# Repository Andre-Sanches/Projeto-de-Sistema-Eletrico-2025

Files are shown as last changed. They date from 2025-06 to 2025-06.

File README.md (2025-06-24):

# Projeto-de-Sistema-Eletrico-2025
Projeto Elétrico exemplo realizado no curso de Engenharia Elétrica - FHO

⚠️ Restrições de Uso  

Este material é fornecido "no estado em que se encontra" e destina-se unicamente a consulta. Qualquer uso comercial, seja direto ou indireto, é estritamente proibido sem autorização expressa do autor.
Para outras finalidades ou solicitações de uso que não se enquadrem nas condições de uso acadêmico e não comercial, por favor, entre em contato com o autor.

✉️ Contato

André Rodrigues Sanches
Seu Email: andrerodriguessanches@hotmail.com
LinkedIn: www.linkedin.com/in/andre-rodrigues-sanches

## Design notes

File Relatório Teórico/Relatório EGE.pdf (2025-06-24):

1

CENTRO UNIVERSITÁRIO DA FUNDAÇÃO HERMÍNIO OMETTO NÚCLEO

DE ENGENHARIA

ENGENHARIA ELÉTRICA

Projetos de sistemas elétricos

Projeto elétrico de uma indústria de papel

Nome completo | RA
André Rodrigues Sanches | 109177
Gabriel Henrique Leme | 109551
Gustavo Ferreira | 110353
Matheus de Souza Cardoso | 108925

Araras

Junho 2025

### 1. INTRODUÇÃO

A energia elétrica tornou-se fundamental na vida das pessoas. Só no Brasil, segundo o

IBGE, 99,8% das residências brasileiras possuem acesso à energia elétrica, consequentemente,

a busca por profissionais que executam serviços de instalações elétricas ficaram cada vez

maiores. As instalações elétricas são compostas por diversos elementos, que vão desde

condutores básicos em qualquer instalação até dispositivos de automação, aplicados em

instalações mais complexas. O conhecimento desses elementos e de sua forma correta de

utilização é necessário aos projetistas para garantir instalações confortáveis e seguras a seus

usuários.

A segurança das instalações elétricas é um aspecto fundamental e está previsto em

algumas normas brasileiras. As normas existem para padronizar, trazer igualdade às instalações

elétricas e melhorar o âmbito de qualidade das mesmas e foi criada justamente para garantir a

segurança de equipamentos e pessoas (SILVA et al., 2019)

Como base, utilizamos da NBR5410:2004, que existe para regulamentar a execução dos

projetos elétricos em baixa tensão, ela surgiu pela preocupação com este tipo de instalação e

traz em suas especificações as justas explicações e vantagens quanto as instalações prediais que

atendem e seguem regularmente a norma. A mesma se aplica principalmente às instalações

elétricas de edificações, qualquer que seja seu uso (residencial, comercial, público, industrial,

de serviços, agropecuário, hortigranjeiro etc.), incluindo as pré-fabricadas, sejam instalações

novas ou reformas

É imprescindível ter certeza de realizar o processo de dimensionamento e execução de

instalação elétrica de maneira correta e com segurança para evitar futuros problemas, pois estes

processos uma vez feitos de maneira imprudente podem ocasionar diversos transtornos durante

e após construção (PORTE, 2018).

Portanto, este relatório detalha o projeto elétrico de uma pequena indústria de papel,

estruturada em três áreas produtivas distintas. O relatório visa abranger desde o

dimensionamento de condutores e dispositivos de proteção até a análise de curtos-circuitos e o

projeto luminotécnico de uma das áreas. A relevância desse relatório simulando o real retrata

para a Engenharia de Segurança do Trabalho a minimização de riscos de acidentes e falhas

operacionais, promovendo um ambiente de trabalho seguro, além disso, para a instituição

representa a aplicação prática e integrada de conhecimentos teóricos estudados em todo

decorrer do curso.

### 2. DESENVOLVIMENTO

### 2.1 Dados iniciais do cliente

Como base para o início do projeto do cliente é fundamental o entendimento das áreas

e dados solicitados pelo mesmo. Abaixo segue tais descrições:

Figura 1 - Distribuição de setores dentro da indústria de papel

Figura 2 - Dados do cliente

### 2.2 Motores

A partir do conhecimento dos dados iniciais do cliente, é começado o dimensionamento

dos equipamentos do projeto.

O grupo responsável pelo projeto, buscou adequar o melhor modelo de motor para a

instalação na planta industrial. O modelo escolhido para as operações é a linha de motores

trifásica de 4 polos W22 IR3 Premium. De acordo com o site do fornecedor, a linha W22 IR3

Premium atende aos níveis de rendimento especificados na Portaria Interministerial n.º 1, de 29

de junho de 2017, que determina o nível mínimo de rendimento em IR3 (faixa de potência de

0,16 a 500 Cv, de 2 a 8 polos), válido para todos os motores comercializados. Também atendem

à norma ABNT NBR 17094 e às legislações anteriores." (WEG, 2022, p. 3). Portanto, a linha

de modelos atende adequadamente a potência necessária na planta industrial.

Figura 3 - Motores WEG

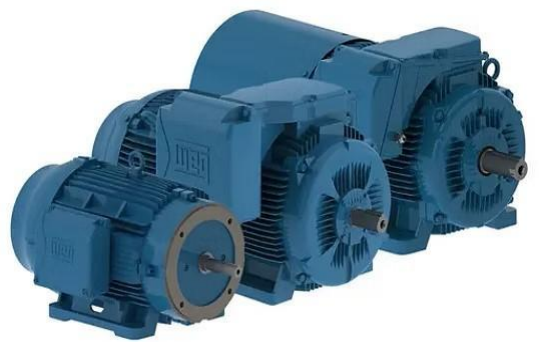
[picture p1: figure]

Fonte: WEG

Com os devidos modelos de motores escolhidos, os dados técnicos dos mesmos

fornecidos pelo fabricante via site, serão utilizados para o preenchimento da tabela de carga

inicial, tendo em vista que os motores trabalharam com fator de potência e rendimento em plena

carga. Abaixo segue os dados obtidos:

Quadro 1 - Dados de Carga Inicial

Fonte: Autoria do grupo

### 2.3. Condutores

Para o cálculo do dimensionamento dos condutores, foi utilizado o método da

ampacidade, que consiste no critério da capacidade de condução de corrente determinando a

menor seção nominal de forma que a corrente que deve circular pelo circuito, a chamada

corrente de projeto, não provoque um aquecimento excessivo nos condutores. Isto é, não leve

os condutores a uma temperatura acima de 70° C para os fios e cabos com isolação de PVC e

de 90° C para os isolados com EPR e XLPE.

O grupo responsável seguiu etapas para o dimensionamento dos condutores, levando

em conta o cálculo da corrente de projeto, método de instalação, aplicação de fatores de

correção apropriados (temperatura e agrupamento), correção de corrente de projeto e seleção

da secção do condutor via dados do fabricante.

A NBR5410 estabelece um total de 75 métodos diferentes de instalação de condutores.

Dependendo do método de instalação, maior ou menor será a capacidade de dissipação de calor

gerado pela passagem da corrente elétrica e, por consequência, maior ou menor será a

capacidade de condução dos condutores. O grupo responsável pelo projeto optou pelos

seguintes métodos:

Para o circuito principal QGF - Método B1, Cabos unipolares ou cabo multipolar em

canaleta ventilada encaixada no piso ou no solo.

Figura 4 - Representação do método de instalação (B1)

Fonte: NBR 5410

Para os demais circuitos áreas e motores - método F (unipolar) e método E (multipolar),

canaleta fechada no piso, solo ou parede.

Figura 5 - Representação do método de instalação

Fonte: NBR 5410

Em relação ao fator de correção por temperatura, o grupo adotou a temperatura ambiente

de 30 °C já que é a média anual da cidade de Curitiba, na qual se localiza a indústria de papel

projetada. De acordo com a norma NBR 5410, para essa condição, não é necessário aplicar fator

de correção à corrente de projeto, uma vez que 30 °C é considerada a temperatura de referência.

A respeito do fator de agrupamento, conforme estabelece a norma NBR 5410, quando

condutores são instalados em grupos (como em eletrodutos, leitos ou bandejas compartilhadas

etc.), é necessário aplicar um fator de correção à corrente de projeto, a fim de considerar a

redução da dissipação térmica.

O valor do fator de agrupamento depende da quantidade de circuitos agrupados, tipo de

instalação e forma de distribuição dos cabos.

Figura 6 - Fatores de correção para agrupamento de circuitos ou cabos multipolares

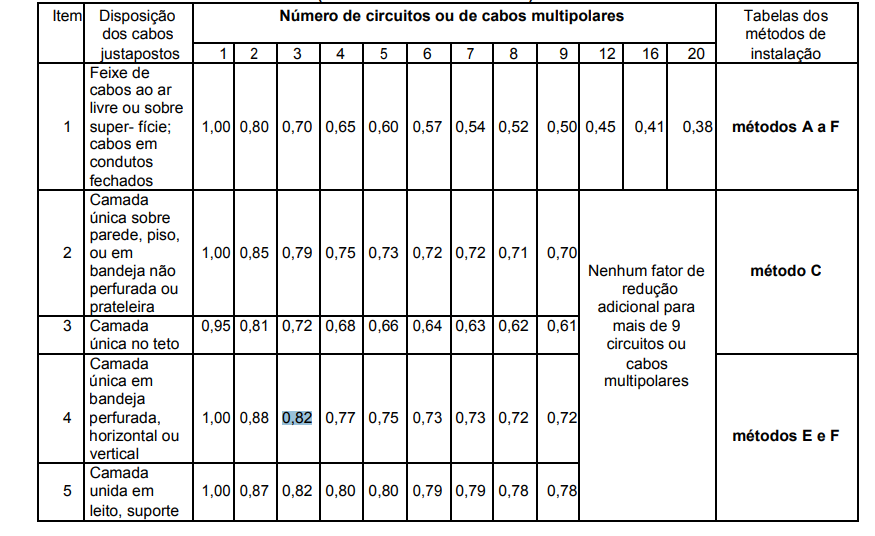
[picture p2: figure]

Fonte: NBR 5410

No projeto da indústria ficou determinado as seguintes formas de agrupamento:

- Para o circuito geral QGF – 1 circuito, com FCA= 1;
- Para as áreas 1,2,3 – 3 Circuitos; com FCA = 0,82;
- Paras os motores – 12 circuitos (Considerando futuras expansões); com FCA =

0,78.

Com os fatores de temperatura e agrupamento definidos, o grupo responsável

pelo projeto realizou os cálculos para a escolha das secções dos cabos para todo sistema da

indústria. Abaixo segue a tabela dos resultados obtidos para os dimensionamentos dos

condutores.

Quadro 2 - Dados para dimensionamento das secções dos condutores

Fonte: Autoria do grupo

A escolha final das seções dos cabos foi realizada com base nas correntes corrigidas e

nas tabelas de fabricantes, assegurando segurança, eficiência e viabilidade técnica para o

funcionamento contínuo e confiável do sistema. Os condutores selecionados são de cobre com

isolação em PVC, oferecendo boa performance elétrica e resistência mecânica para o ambiente

industrial projetado.

Para o ponto de alimentação do QGF:

Quadro 3 - Secção condutores selecionados para a alimentação do QGF

Fonte: Autoria do grupo

Para o ponto de alimentação que liga o QGF as áreas:

Quadro 4 - Secção condutores selecionados para a alimentação que liga QGF as áreas 1,2 e 3

Fonte: Autoria do grupo

Para o ponto de alimentação que liga os motores:

Quadro 5 - Secção de condutores selecionados para a alimentação dos motores

Fonte: Autoria do grupo

Com os resultados obtidos a seleção dos condutores atende integralmente às exigências

normativas e técnicas, contribuindo para a segurança, durabilidade e eficiência da instalação

elétrica da indústria.

### 2.4 Disjuntores

Após a realização do dimensionamento dos condutores do projeto, a próxima

etapa de cálculos é a definição dos dispositivos de proteção desses condutores contra curtos-

circuitos e sobrecargas, a fim de prevenir riscos de incêndio, danos materiais e choques

elétricos.

De acordo com a norma NBR 5410:2004, o projeto deve prever dispositivos de

proteção que assegurem a integridade dos condutores e a continuidade do fornecimento de

energia elétrica de forma segura e eficiente. O dimensionamento dos disjuntores deve estar

alinhado à corrente de projeto do circuito, ao tipo de carga, ao tempo de atuação desejado, e às

características de coordenação com os condutores e demais dispositivos.

A escolha dos disjuntores ideais para os pontos do projeto, foi definida a partir

da corrente de projeto do circuito, obtida a partir da potência total das cargas, da tensão de

alimentação e do fator de potência. Com isso, foi selecionado um modelo cuja corrente nominal

(In) e superior à corrente de projeto (Ip), não ultrapassando a capacidade de condução do

condutor (Iz). Além disso, foi aplicado os devidos fatores de correção a temperatura e

agrupamento, uma vez que esses impactam diretamente a corrente corrigida, que por sua vez

influencia a escolha do disjuntor. Por fim, foi verificado a capacidade interrupção do disjuntor,

curva de disparo e a seletividade, já que essas garantem a atuação correta e segura dos

disjuntores frente a falhas, como curto-circuito.

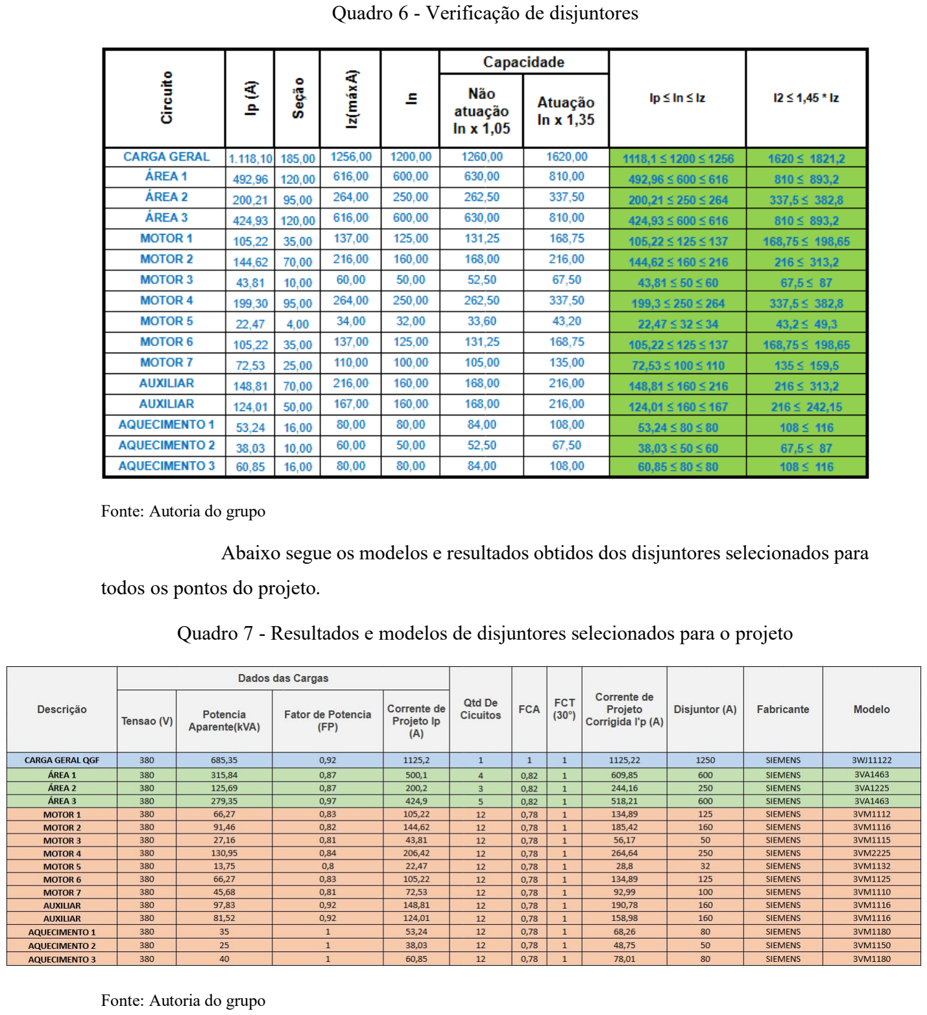
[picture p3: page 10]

Quadro 6 - Verificação de disjuntores

Fonte: Autoria do grupo

Abaixo segue os modelos e resultados obtidos dos disjuntores selecionados para

todos os pontos do projeto.

Quadro 7 - Resultados e modelos de disjuntores selecionados para o projeto

Fonte: Autoria do grupo

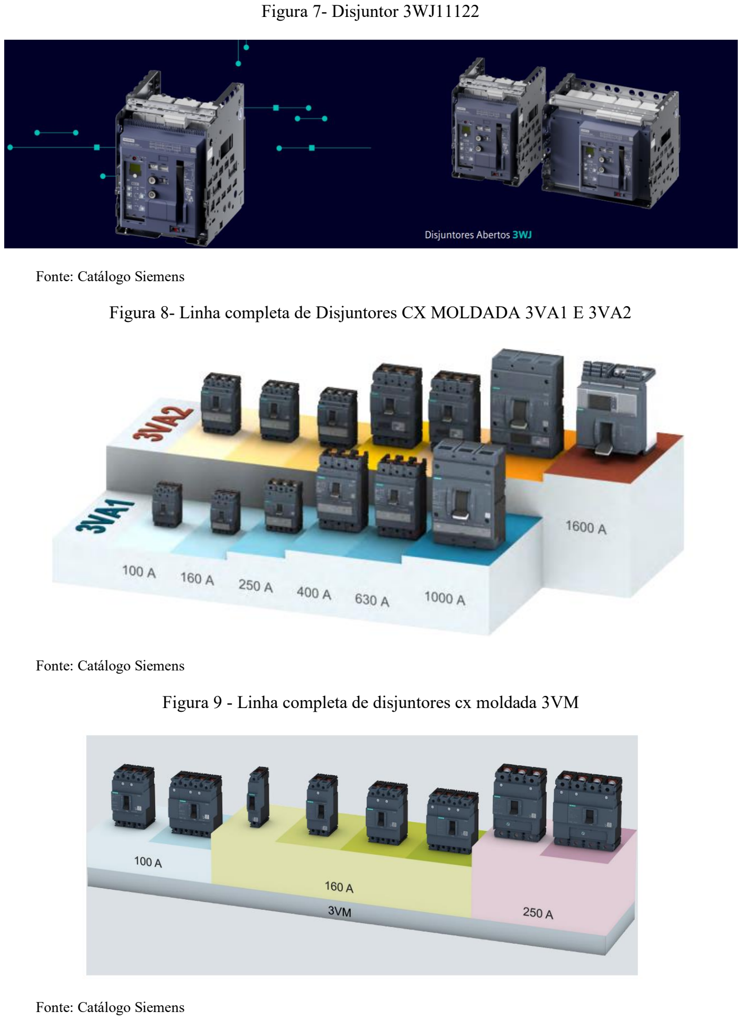
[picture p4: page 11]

Figura 7- Disjuntor 3WJ11122

Fonte: Catálogo Siemens

Figura 8- Linha completa de Disjuntores CX MOLDADA 3VA1 E 3VA2

Fonte: Catálogo Siemens

Figura 9 - Linha completa de disjuntores cx moldada 3VM

Fonte: Catálogo Siemens

Os modelos selecionados atendem tanto aos requisitos técnicos quanto normativos,

proporcionando confiabilidade, segurança operacional e continuidade no fornecimento de

energia elétrica. O grupo responsável optou por apresentar apenas os aspectos gerais dos

disjuntores, não se aprofundando em dados mais técnicos da construção dos mesmos. Em caso,

de maiores especificações consultar o site ou próprio catálogo dos modelos especificados.

Assim, os resultados obtidos refletem um dimensionamento criterioso e coerente com

as condições reais da instalação, garantindo integridade da rede elétrica como um todo.

### 2.5 Análise de curto circuito

A análise de curto-circuito é uma etapa fundamental para o dimensionamento dentro

do projeto, já que a partir dela é possível identificar níveis de corrente de falta em diferentes

pontos do sistema. A partir dos resultados e análise pode-se definir a correta especificação dos

dispositivos de proteção, condutores e barramentos do sistema. Além disso, garante a segurança

dos trabalhadores que estarão envolvidos em futuras manutenções e na instalação como um

todo.

De acordo com a NBR 5410, as correntes de curto-circuito devem ser determinadas para

possibilitar o correto dimensionamento dos dispositivos de proteção, que devem possuir

capacidade de interrupção compatível com a corrente de curto-circuito presumida no ponto da

instalação (ABNT, 2004, NBR 5410, item 6.5.3.2.2). Da mesma forma, a norma NBR 14039,

descreve que devem ser considerados os valores de corrente de curto-circuito trifásica e

monofásica no dimensionamento da instalação e escolha dos equipamentos, levando-se em

conta as componentes simétricas e assimétricas (ABNT, 2005, NBR 14039, item 5.3.3 e 6.1.1).

Por fim, a NR10 prevê que em instalações elétricas deve conter a documentação atualizada,

contemplando estudos de curto-circuito, seletividade, coordenação e proteção.

Seguindo as normas descritas, a tabela de análise de curto-circuito do projeto da

indústria de papel foi realizada, contemplando os valores calculados de corrente de curto-

circuito em diversos pontos da instalação, incluindo o ponto de entrega, o secundário do

transformador, o Quadro Geral de Força (QGF) e os barramentos das áreas 1, 2 e 3.

O grupo responsável pelo projeto, utilizou o simulador PSP-UFU para realizar as

devidas análises de corrente de curto-circuito. Abaixo e demostrado a imagem do sistema para

início das análises.

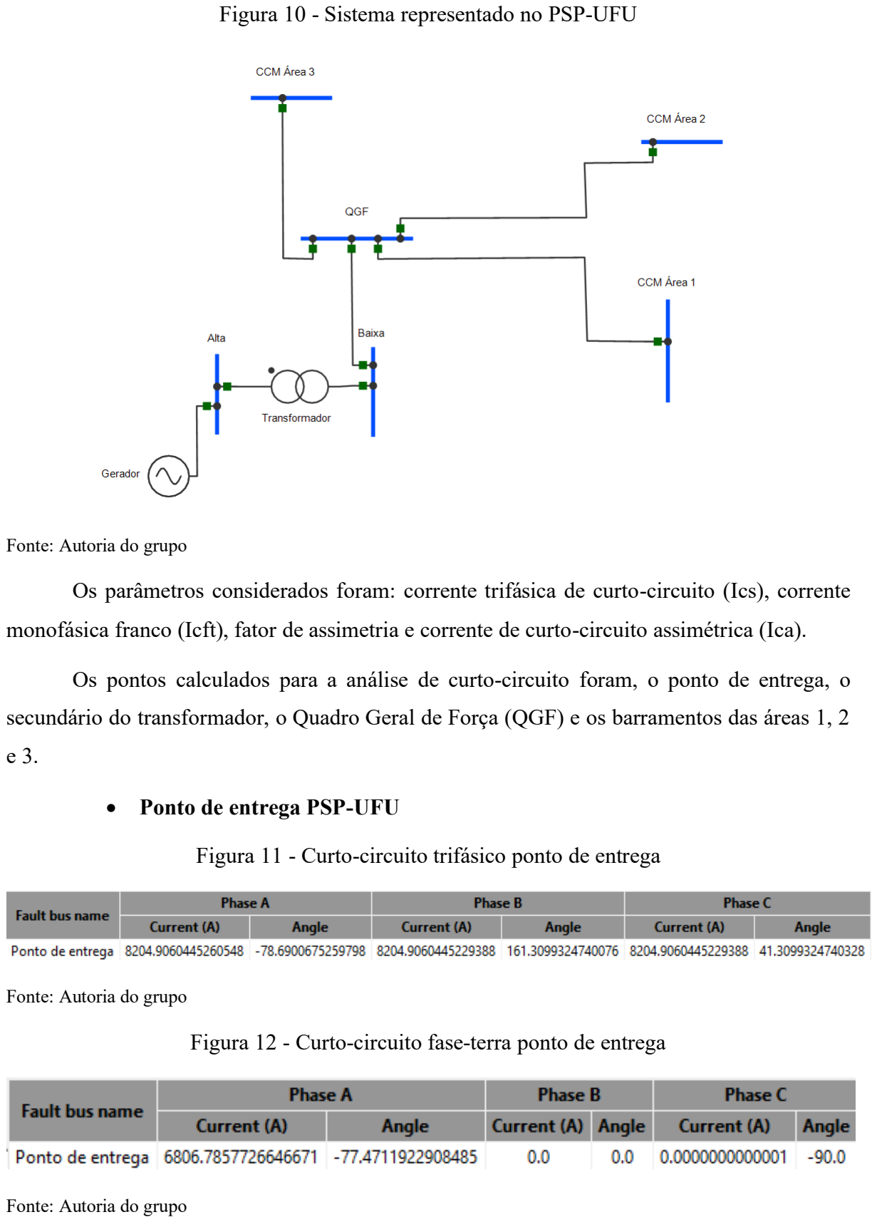
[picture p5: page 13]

Figura 10 - Sistema representado no PSP-UFU

Fonte: Autoria do grupo

Os parâmetros considerados foram: corrente trifásica de curto-circuito (Ics), corrente

monofásica franco (Icft), fator de assimetria e corrente de curto-circuito assimétrica (Ica).

Os pontos calculados para a análise de curto-circuito foram, o ponto de entrega, o

secundário do transformador, o Quadro Geral de Força (QGF) e os barramentos das áreas 1, 2

e 3.

- Ponto de entrega PSP-UFU

Figura 11 - Curto-circuito trifásico ponto de entrega

Fonte: Autoria do grupo

Figura 12 - Curto-circuito fase-terra ponto de entrega

Fonte: Autoria do grupo

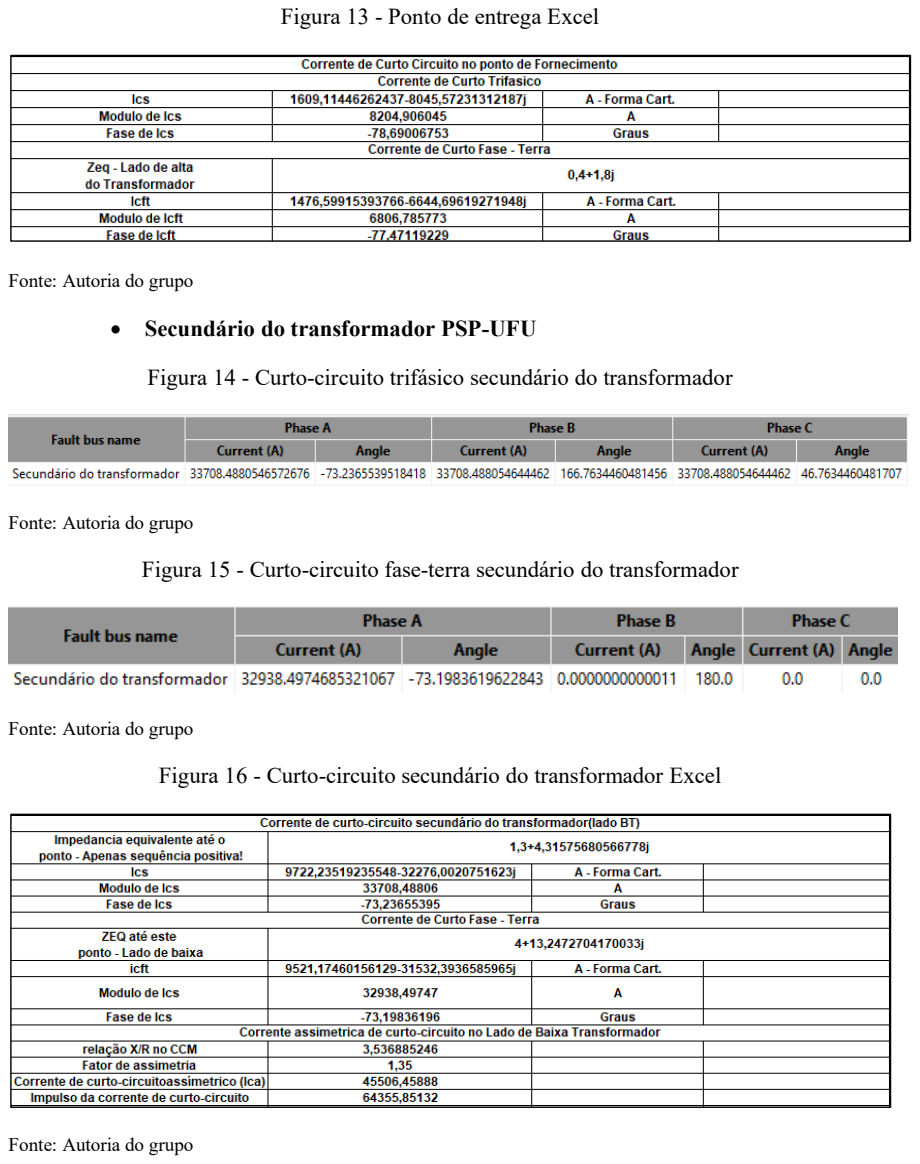
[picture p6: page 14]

Figura 13 - Ponto de entrega Excel

Fonte: Autoria do grupo

- Secundário do transformador PSP-UFU

Figura 14 - Curto-circuito trifásico secundário do transformador

Fonte: Autoria do grupo

Figura 15 - Curto-circuito fase-terra secundário do transformador

Fonte: Autoria do grupo

Figura 16 - Curto-circuito secundário do transformador Excel

Fonte: Autoria do grupo

- QGF PSP-UFU

Figura 17 - Curto-circuito trifásico QGF

Fonte: Autoria do grupo

Figura 18 - Curto-circuito fase-terra QGF

Fonte: Autoria do grupo

Figura 19 - Curto-circuito QGF Excel

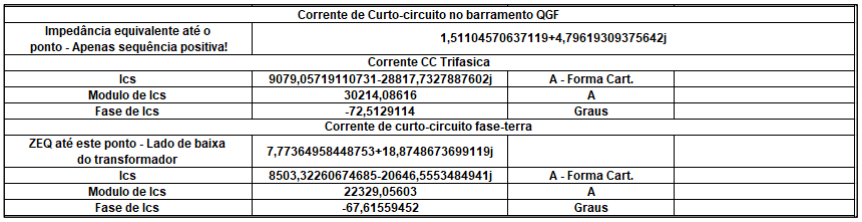
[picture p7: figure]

Fonte: Autoria do grupo

- CCM ÁREA 1 PSP-UFU

Figura 20 - Curto-circuito trifásico CCM área 1

Fonte: Autoria do grupo

Figura 21 - Curto-circuito fase-terra CCM área 1

Fonte: Autoria do grupo

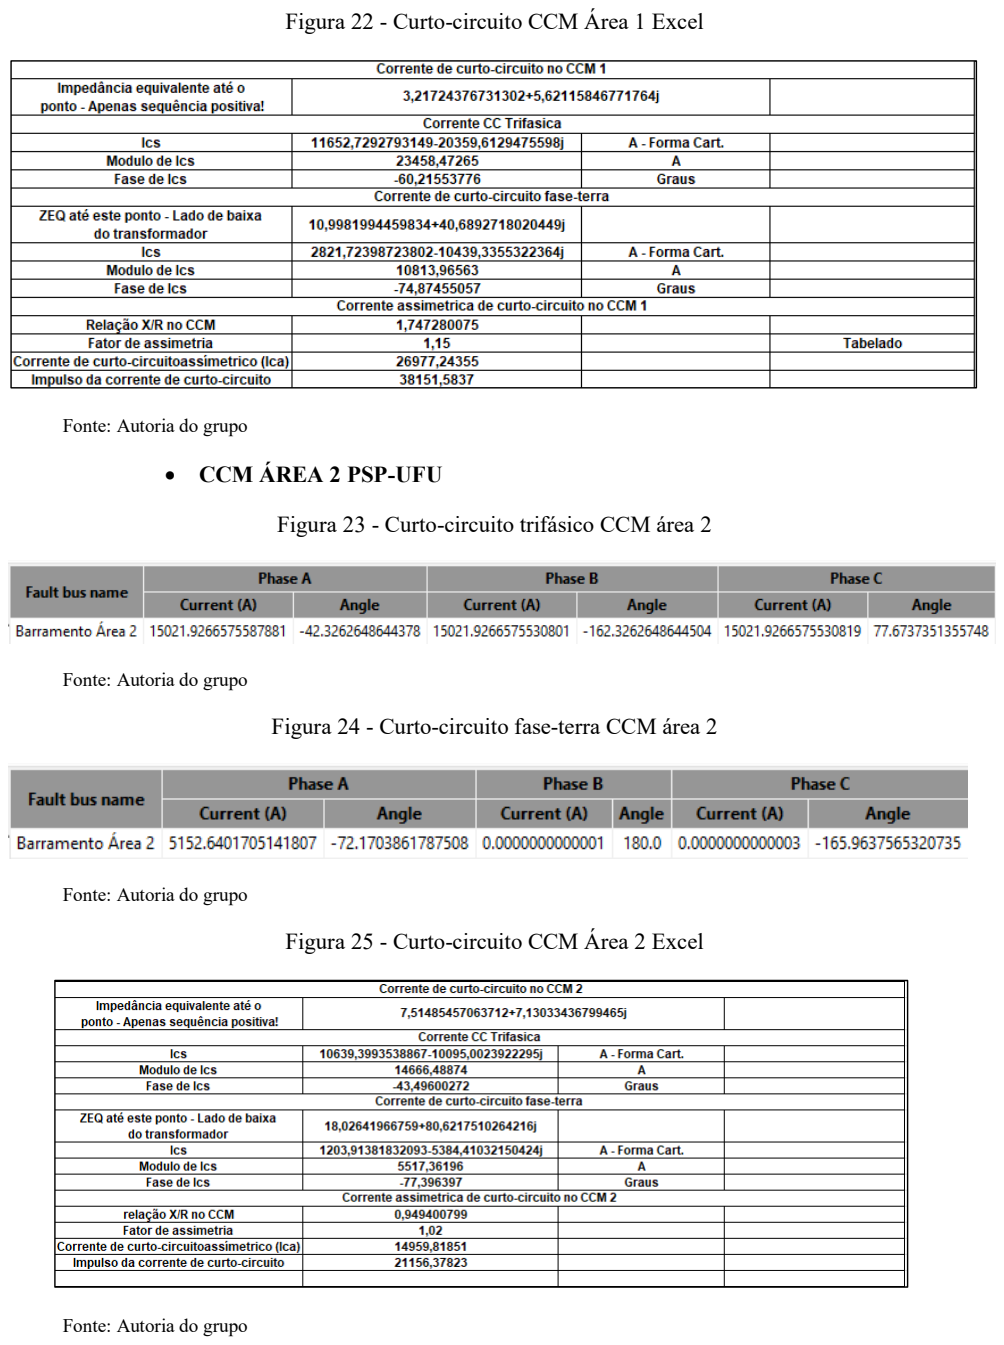
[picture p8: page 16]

Figura 22 - Curto-circuito CCM Área 1 Excel

Fonte: Autoria do grupo

- CCM ÁREA 2 PSP-UFU

Figura 23 - Curto-circuito trifásico CCM área 2

Fonte: Autoria do grupo

Figura 24 - Curto-circuito fase-terra CCM área 2

Fonte: Autoria do grupo

Figura 25 - Curto-circuito CCM Área 2 Excel

Fonte: Autoria do grupo

- CCM ÁREA 3 PSP-UFU

Figura 26 - Curto-circuito trifásico CCM área 3

Fonte: Autoria do grupo

Figura 27 - Curto-circuito fase-terra CCM área 3

Fonte: Autoria do grupo

Figura 28 - Curto-circuito CCM Área 3 Excel

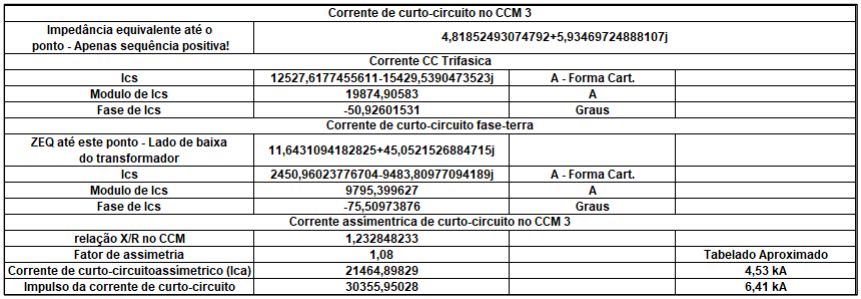
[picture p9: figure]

Fonte: Autoria do grupo

Os valores de impedância dos cabos, sequência positiva, negativa (Iguais) e sequência

zero foram obtidos via fabricante, valores esses que foram utilizados para calcular a corrente

de curto-circuito trifásico e fase-terra dos pontos citados via simulador. Além disso as demais

impedâncias utilizadas na simulação podem ser encontradas na figura de dados do cliente

(Figura 2).

Quadro 8 - Valores de impedância de sequência positiva, negativa e zero dos condutores

Fonte: Induscabos

Os valores dos cálculos de cada ponto e apresentado na tabela abaixo:

Quadro 9 - Corrente de curto-circuito

Fonte: Autoria do grupo

No ponto de entrega, a corrente trifásica foi de 8,20 kA, enquanto a corrente monofásica

atingiu 6,81 kA, com fator de assimetria de 50,0 e corrente assimétrica de 1,69 kA. Já no

secundário do transformador, ponto mais crítico da instalação, a corrente trifásica chegou a

33,71 kA e a monofásica a 32,94 kA, com fator de assimetria de 3,53 e corrente assimétrica de

1,35 kA. O QGF apresentou valores semelhantes, com 30,21 kA trifásico e 22,32 kA

monofásico.

Já nos barramentos das áreas 1, 2 e 3, foi observado a queda progressiva das correntes

de curto-circuito, devido às perdas por impedância ao longo da rede. Na área 1, os valores foram

23,45 kA (Ics) e 10,81 kA (Icft). Na área 2, 14,67 kA e 5,52 kA respectivamente. Por fim, na

área 3, 19,87 kA e 9,8 kA, com fatores de assimetria variando entre 0,94 e 1,74.

A análise foi realizada conforme as diretrizes das normas NBR 5410 e NBR 14039, que

estabelecem critérios para o dimensionamento de dispositivos de proteção e condutores com

base nos valores de curto-circuito. Com isso, notou-se que o ponto mais crítico da instalação é

o secundário do transformador, onde foi registrada a maior corrente trifásica de curto-circuito

(33,71 kA) e corrente franco monofásica de 32,94 kA, com fator de assimetria elevado. Esse

valor indica a necessidade de dispositivos com alto Poder de Interrupção (PDI), além de

cuidados especiais com a seletividade e coordenação da proteção, já o menor ponto de curto-circuito foi o barramento da Área 2, com corrente trifásica de 14,67 kA e corrente franco

monofásica de 5,52 kA, isso se deu devido à distância elétrica maior do centro de transformação

e o efeito das impedâncias ao longo do circuito.

Portanto conclui-se, que o sistema analisado apresenta níveis de curto-circuito

compatíveis com as exigências normativas, podendo ser cabível um estudo de seletividade e

validação computacional mais afundo em pontos como o secundário do transformador, já que

demostrou maior incidência de corrente de curto curto-circuito.

### 2.6 Inversores

Com os motores dimensionados, juntamente com condutores e dispositivos de proteção

cabe ao grupo responsável pelo projeto a escolha dos modelos de inversores para os motores

que a indústria de papel irá utilizar em sua operação.

A empresa optou por inversores como chave de partida, já que em sua operação será

necessário o controle de velocidade e torque dos motores. O grupo responsável escolheu em

seguir o mesmo fabricante dos motores para os inversores, neste caso o fabricante será a WEG.

Cada motor da operação terá seu inversor individualmente. Os inversores deverão ser

parametrizados conforme os dados do motor como exemplo: potência, corrente nominal,

tensão, rampa de aceleração, RPM, frequência e demais dados se necessária integração a rede

de automação.

O grupo responsável escolheu a linha CFW11 da WEG para os motores, a linha da WEG

conta com excelentes qualidades em performance, robustez, tecnologia e longevidade, fatores

esses indispensáveis em um ambiente industrial.

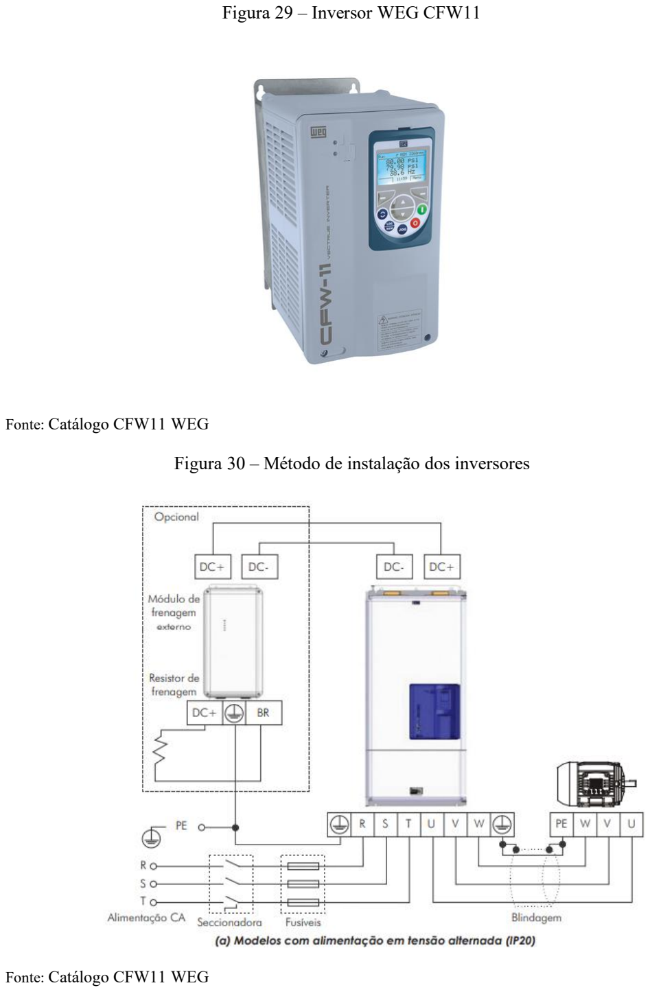
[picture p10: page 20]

Figura 29 – Inversor WEG CFW11

Fonte: Catálogo CFW11 WEG

Figura 30 – Método de instalação dos inversores

Fonte: Catálogo CFW11 WEG

Os inversores foram dimensionados levando em conta a corrente nominal dos motores

a qual serão instalados. Abaixo segue a tabela dos modelos especificados dos inversores e a

tabela fornecida pela própria WEG.

Quadro 10 - Dimensionamento de inversores

Fonte: Autoria do grupo

| DESCRIÇÃO | Tipo Acion. | Dados da Carga | | | Fabricante | Modelo
| Grandezas Elétricas | Fp | Rend. (η) | FS AREA | Ip(A) Tensao(V)
(kW) | (CV) | (kVAr) | (kVA)
1 | MOTOR 1 | INVERSOR | 380 | 55,00 | 75,00 | 30,68 | 66,27 | 0,83 | 0,96 | 1,25 | 105,22 | WEG | CFW110105T4ODBZ
| MOTOR 2 | INVERSOR | 380 | 75,00 | 100,00 | 42,93 | 91,46 | 0,82 | 0,962 | 1,25 | 144,62 | WEG | CFW110142T4SZ
| MOTOR 3 | INVERSOR | 380 | 22,00 | 30,00 | 12,90 | 27,16 | 0,81 | 0,943 | 1,25 | 43,81 | WEG | CFW110045T4SZ
| MOTOR 4 | INVERSOR | 380 | 110,00 | 150,00 | 59,68 | 130,95 | 0,84 | 0,965 | 1,25 | 206,42 | WEG | CFW110211T4SZ
2 | MOTOR 5 | INVERSOR | 380 | 11,00 | 15,00 | 6,60 | 13,75 | 0,80 | 0,931 | 1,25 | 22,47 | WEG | CFW110024T4SZ
| MOTOR 6 | INVERSOR | 380 | 55,00 | 75,00 | 30,68 | 66,27 | 0,83 | 0,958 | 1,25 | 105,22 | WEG | CFW110105T4ODBZ
| MOTOR 7 | INVERSOR | 380 | 37,00 | 50,00 | 21,70 | 45,68 | 0,81 | 0,96 | 1,25 | 72,53 | WEG | CFW110070T4SZ
3 | AUXILIAR | ALIM | 380 | 90,00 | 1,50 | 35,27 | 97,83 | 0,92 | - | - | 148,81 | - | -
| AUXILIAR | ALIM | 380 | 75,00 | 2,00 | 29,39 | 81,52 | 0,92 | - | - | 124,01 | - | -
| AQUECIMENTO 1 | ALIM | 380 | 35,00 | 1,50 | 0,00 | 35,00 | 1,00 | - | - | 53,24 | - | -
| AQUECIMENTO 2 | ALIM | 380 | 25,00 | 20,00 | 0,00 | 25,00 | 1,00 | - | - | 38,03 | - | -
| AQUECIMENTO 3 | ALIM | 380 | 40,00 | 20,00 | 0,00 | 40,00 | 1,00 | - | - | 60,85 | - | -

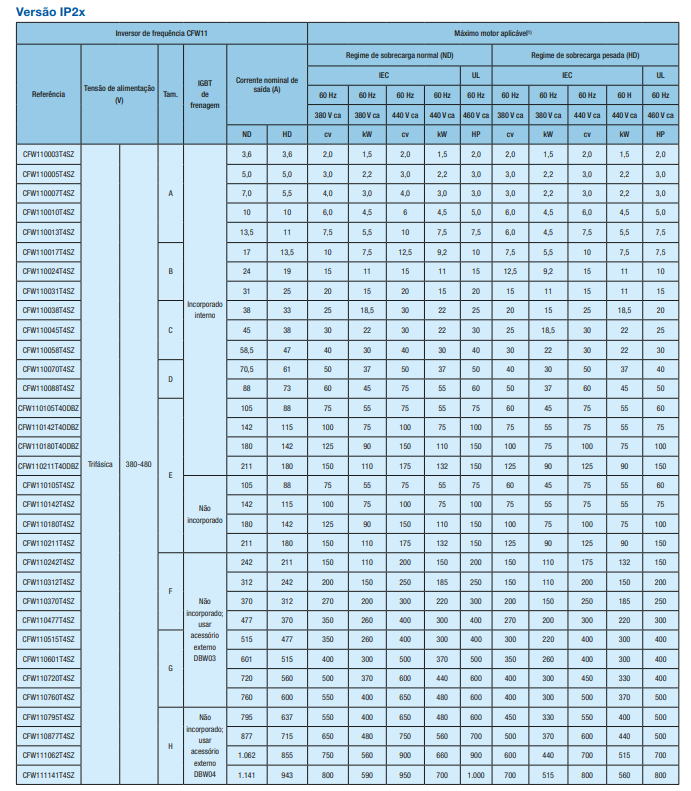
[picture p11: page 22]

Figura 31 - Tabela de especificação inversor CFW11 WEG

Fonte: Manual CFW11 WEG

Figura 32 - Dados da eletrônica/gerais CFW11

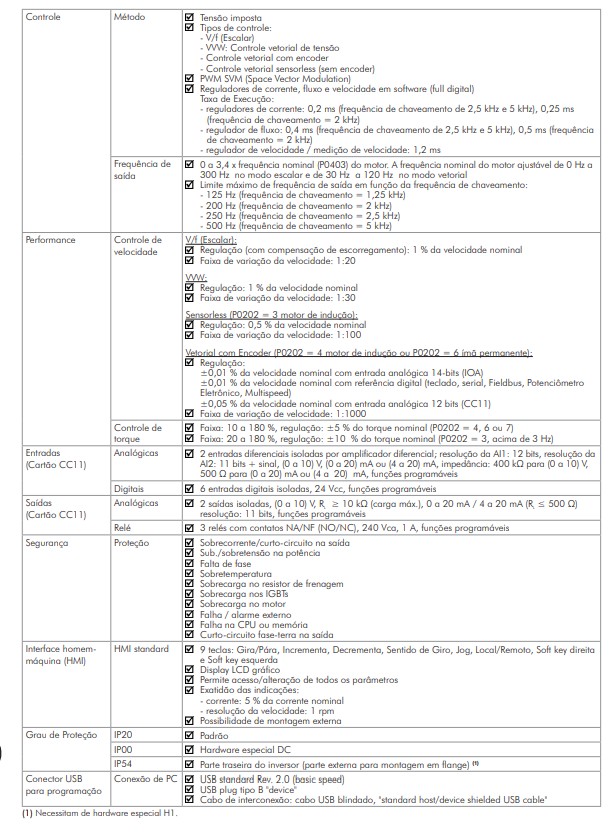
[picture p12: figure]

Fonte: Manual CFW11 WEG

### 2.7 Esquema unifilar

Com os condutores, dispositivos de proteção, motores e acionamentos definidos o grupo

elaborou o seguinte diagrama unifilar da planta da indústria de papel.

Figura 33 - Vista geral do diagrama unifilar

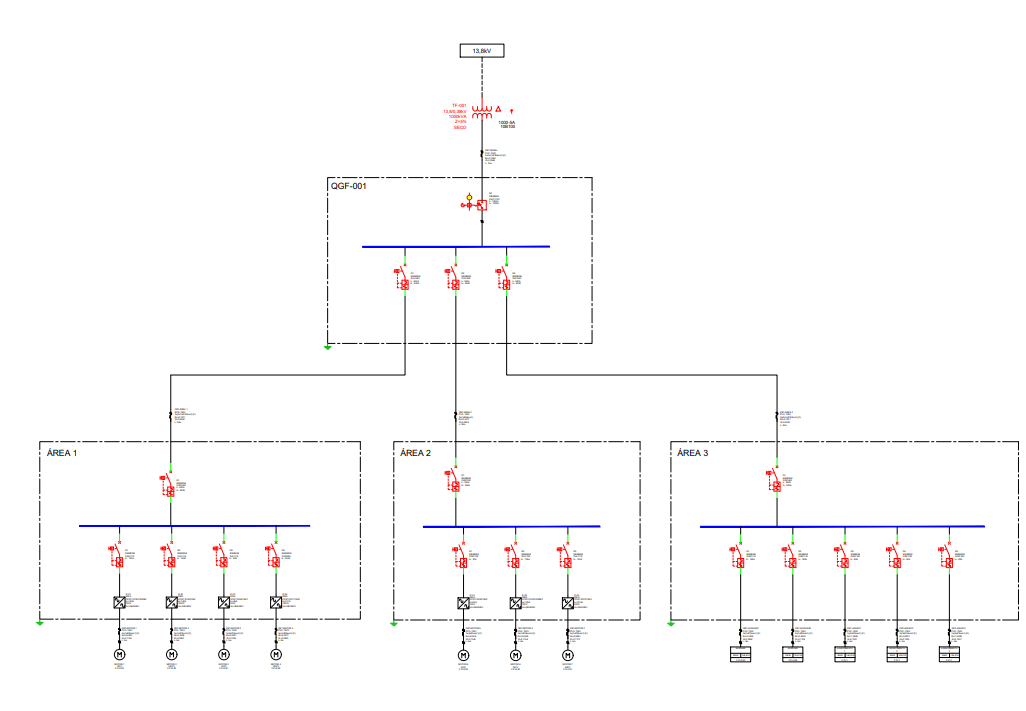
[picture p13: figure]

Fonte: Autoria do grupo

Figura 34 - Vista do diagrama unifilar substacao-QGF1

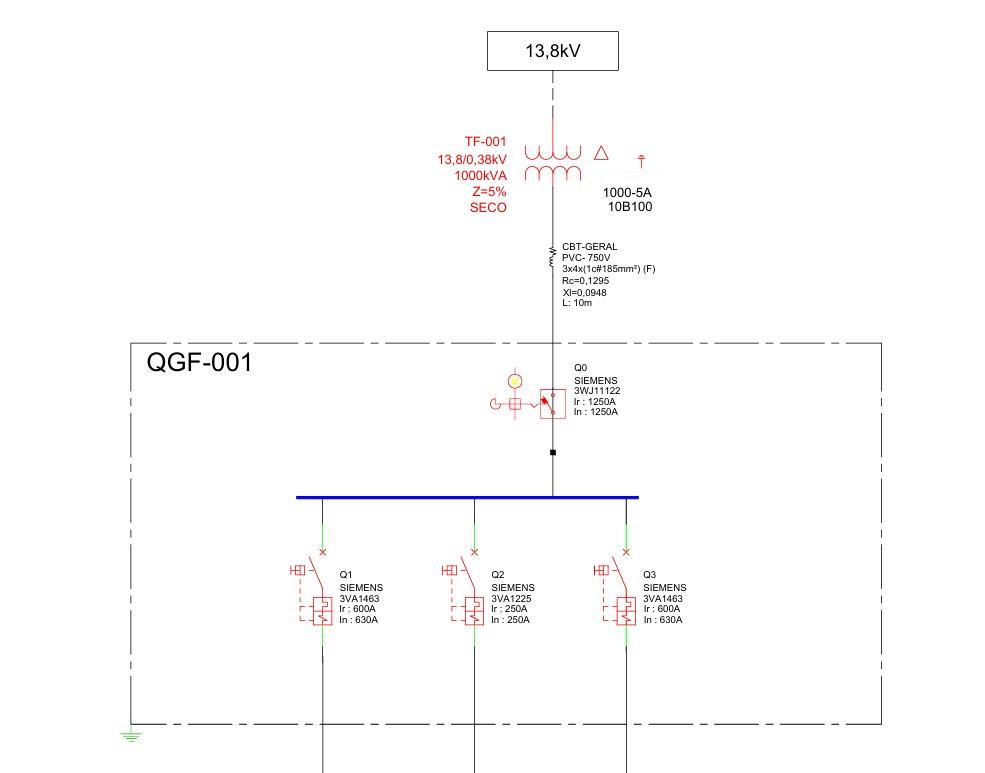
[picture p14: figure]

Fonte: Autoria do grupo

Figura 35 - Vista do diagrama unifilar QGF1 – AREA 1

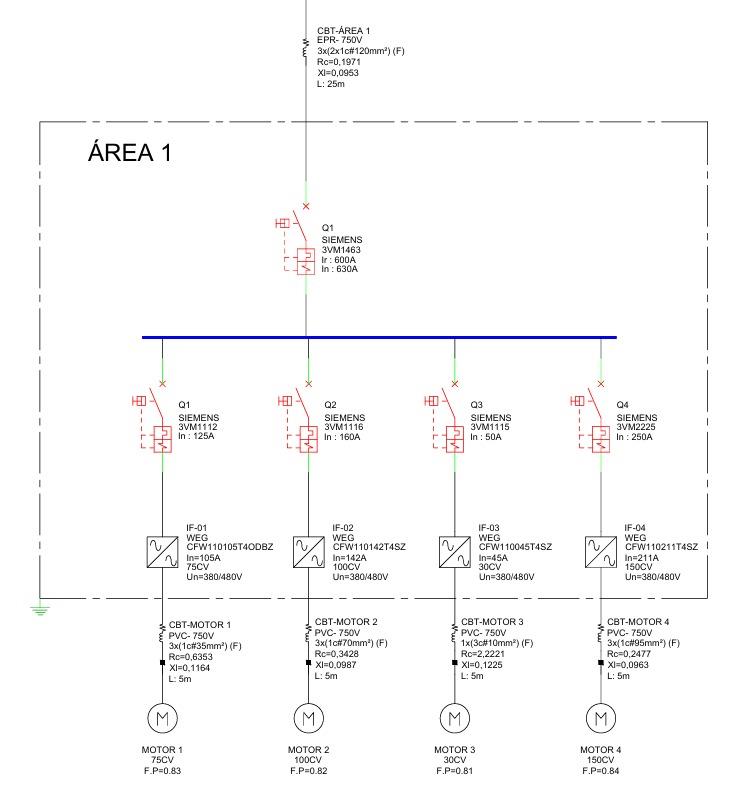
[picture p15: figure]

Fonte: Autoria do grupo

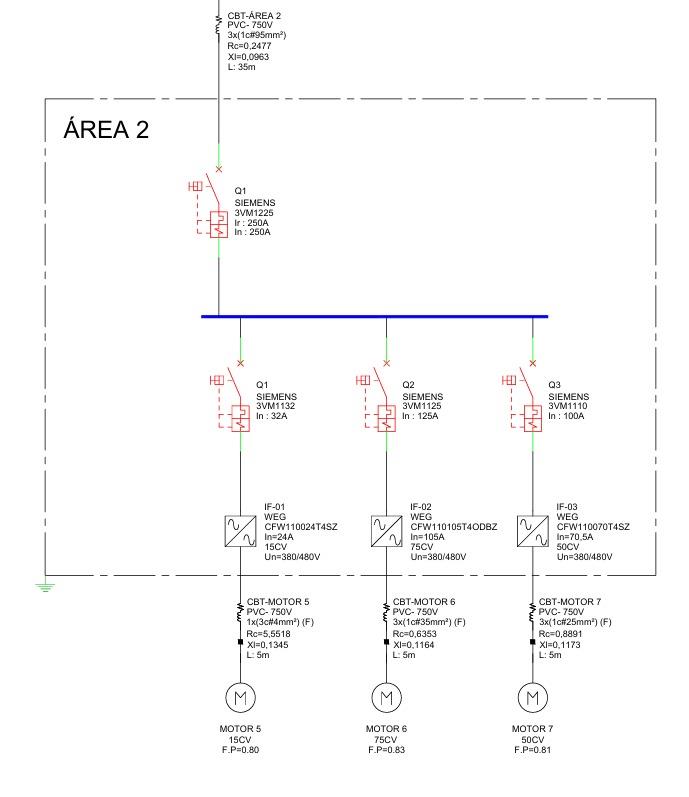
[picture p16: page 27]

Figura 36 - Vista do diagrama unifilar QGF1 – AREA 2

Fonte: Autoria do grupo

Figura 37 - Vista do diagrama unifilar QGF1 – AREA 3

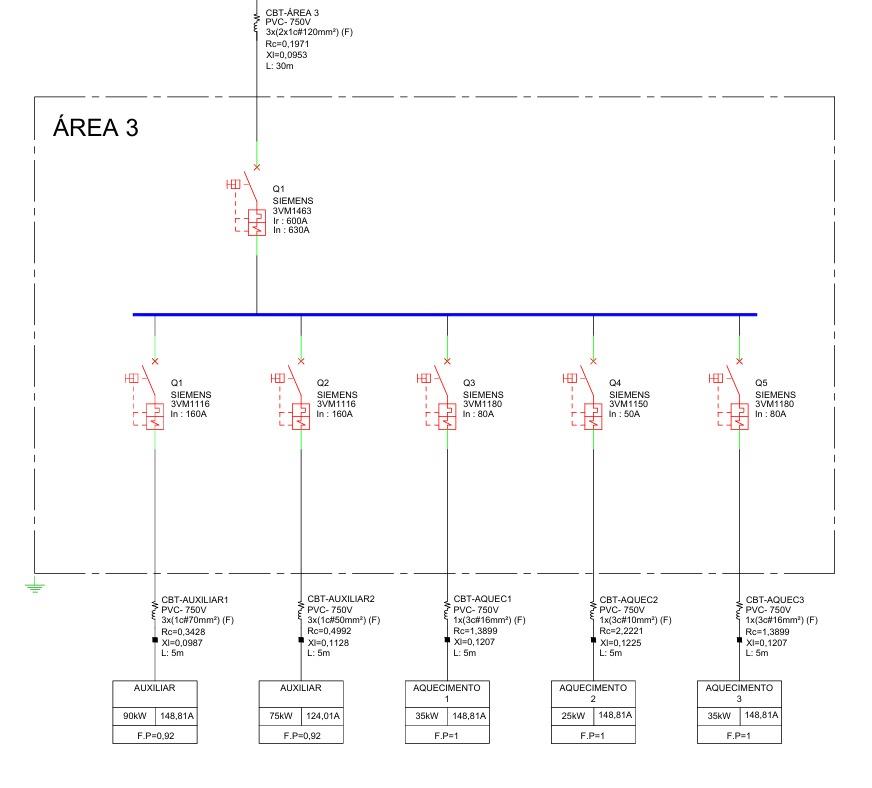
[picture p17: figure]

Fonte: Autoria do grupo

### 2.9 Fator de potência

Para o cálculo do fator de potência geral do projeto foi utilizado a seguinte fórmula

Figura 38 - Fórmula Fator de potência

Pativa = 630 kW

Preativa = 264,38 kVAr

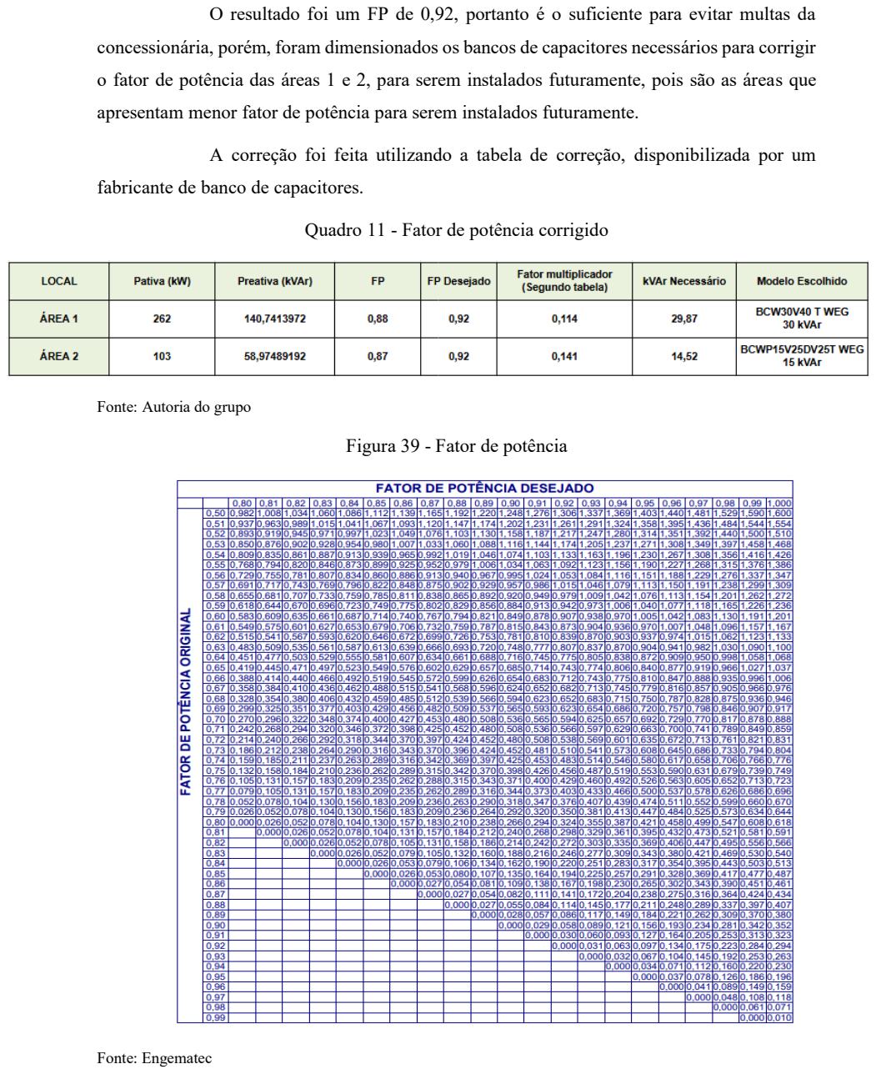
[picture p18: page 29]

O resultado foi um FP de 0,92, portanto é o suficiente para evitar multas da

concessionária, porém, foram dimensionados os bancos de capacitores necessários para corrigir

o fator de potência das áreas 1 e 2, para serem instalados futuramente, pois são as áreas que

apresentam menor fator de potência para serem instalados futuramente.

A correção foi feita utilizando a tabela de correção, disponibilizada por um

fabricante de banco de capacitores.

Quadro 11 - Fator de potência corrigido

Fonte: Autoria do grupo

Figura 39 - Fator de potência

Fonte: Engematec

### 2.10 Especificação do tipo de subestação

Para a escolha de entrada de serviço optou-se pela entrada de serviço subterrânea.

Conforme estabelecido pela Copel NTC 903100, essa escolha se justifica pela maior segurança

operacional, menor impacto visual e proteção dos condutores contra intempéries e danos

externos, garantindo maior confiabilidade e longevidade ao sistema elétrico da indústria. O

projeto de entrada de serviço subterrâneo atende as necessidades de demanda da indústria de

papel.

Figura 40 - Caixas de passagem

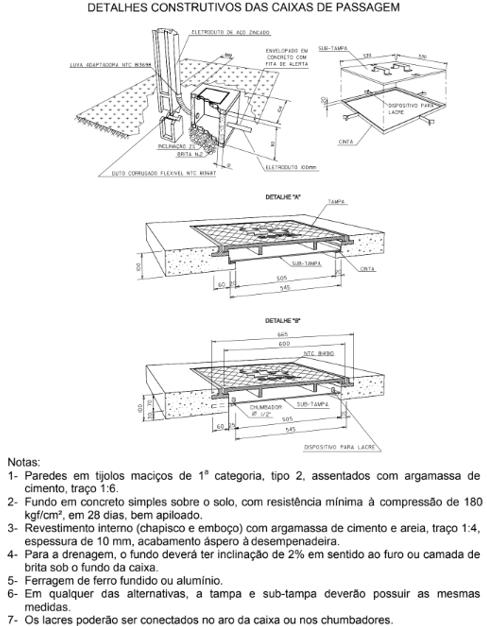
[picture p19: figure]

Fonte: : Copel NTC 903100

A entrada de serviço subterrânea exige caixas de passagem para a acomodação e

proteção dos cabos. Essas caixas de passagem são projetadas para garantir a segurança dos

circuitos de alimentação e facilitar as manutenções futuras, seguindo padrões construtivos

estabelecidos pela NTC 903100 para garantir durabilidade e segurança.

Figura 41 - Subestação

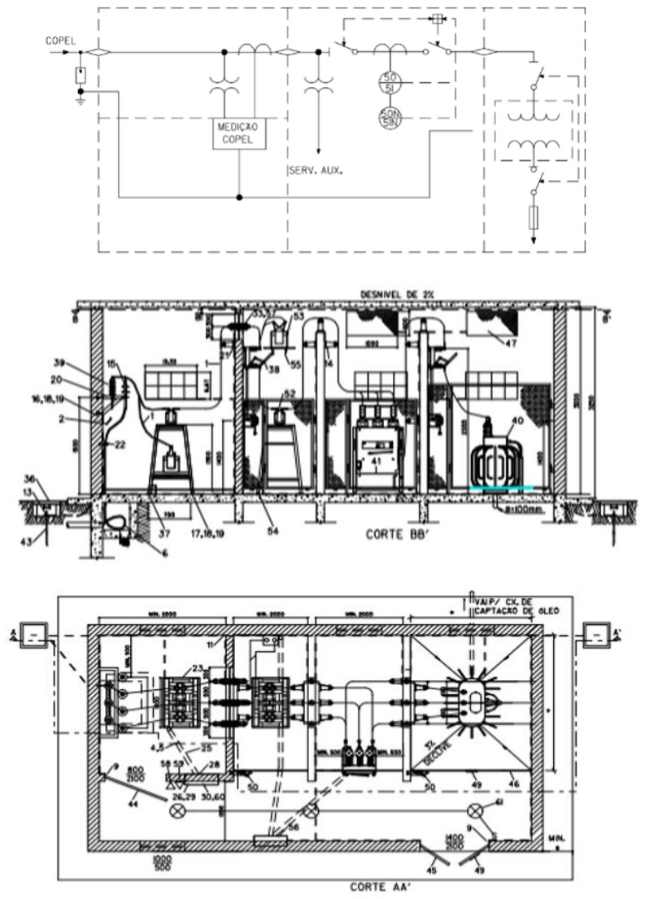
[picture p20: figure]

Fonte: Copel NTC 903100

A caixa de passagem leva os condutores de alimentação até um abrigo, esse abrigo é

projetado para abrigar os módulos de medição, equipamentos de proteção, transformadores de

corrente, transformador de potencial e um transformador de potência, considerando uma

instalação de 1000 kVA com relés secundários, conforme a NTC 903100 da Copel. Esta cabine

é crucial para a segurança e o controle do sistema, garantindo a proteção dos equipamentos e a

medição adequada do consumo de energia.

### 2.11 Transformador

A partir da tabela de cargas, deve se escolher também o modelo ideal de transformador

para atender a alimentação da indústria de papel. O mercado disponibiliza diversos

transformadores, o de escolha do grupo responsável foi o Transformador de potência a Seco

1000.0kVA

Figura 42 - Transformador Seco 1000.0kVA 13.8/0.38kV CST IP -00 NA

Fonte: WEG

Figura 43 - Dados Técnicos Transformador Seco

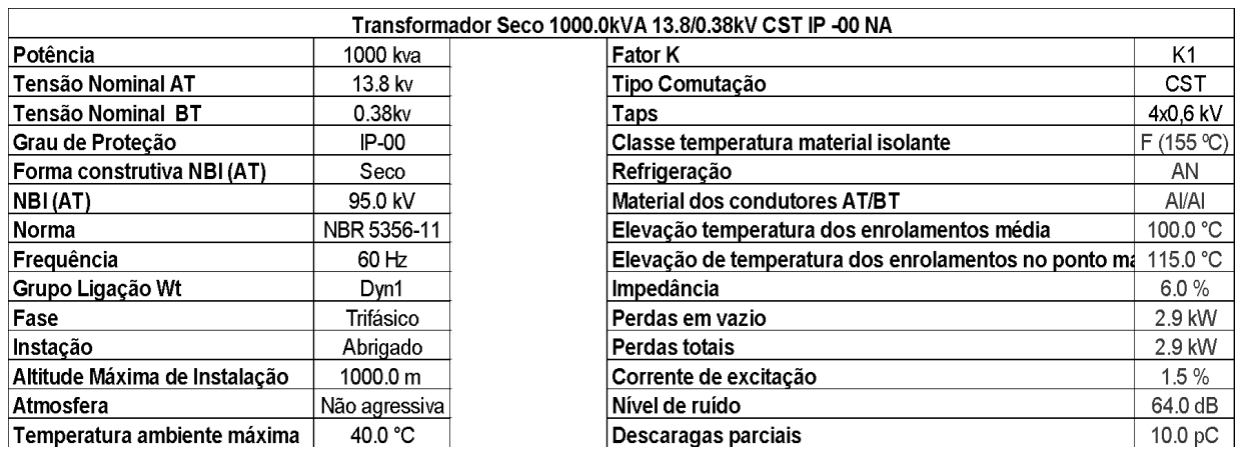
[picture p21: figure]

Fonte: WEG

A escolha do transformador foi baseada no cálculo da demanda total do projeto, que

resultou em um valor de 685kVA, entretanto deve-se considerar um fator de segurança de 25 a

30% (Fator de segurança = 1.25), com isso valor real da demanda corrigido resultou em 872.5

kVA. Desse modo, a escolha do transformador para atender a indústria de papel deve ter

potência superior a 872.5 kVA. O transformador mais próximo que atende esse valor é o

transformador de 1000 kVA.

Além disso, outros fatores para a escolha do transformador a seco foram a segurança,

manutenção e dimensões frente a ambientes abrigados. De acordo com a NBR 5356-11 (ABNT,

2021), transformadores a seco são frequentemente preferidos em instalações abrigadas,

especialmente em ambientes comerciais e industriais, devido à sua segurança contra incêndios.

Como não contêm óleo, eliminam o risco de vazamentos e incêndios associados ao óleo.

Portanto, a escolha se passou pela não utilização do óleo, já que o mesmo traz fatores negativos

em ambientes abrigados, o que não é interessante para área industrial projetada.

Segue abaixo a especificação sumária de todos os equipamentos necessários e

requisitados obrigatoriamente pela Copel, respeitando todos os valores mínimos impostos pela

NTC 903100.

Quadro 12 - Especificação componentes subestação

Fonte: Autoria do grupo

Quadro 13 - Especificação sumária componentes subestação

Fonte: Autoria do grupo

### 2.12 Luminotécnico

O projeto luminotécnico foi desenvolvido para a área A1, designada como escritório

comum, com dimensões de 20 metros de comprimento por 15 metros de largura. As

características do ambiente, que influenciam diretamente no cálculo e na distribuição da luz,

incluem teto de superfície branca, paredes claras e pisos escuros. O objetivo principal deste

projeto foi garantir um nível de iluminação adequado para a atividade de escritório, atendendo

aos requisitos de iluminância média estabelecidos pela norma NBR ISO/CIE 8995-1 para

escritórios.

Para a elaboração e simulação do projeto, foi utilizado o software DIALux evo, uma

ferramenta padrão da indústria que permite análises precisas da distribuição luminosa e dos

resultados quantitativos.

Figura 44 - Dados luminotécnico

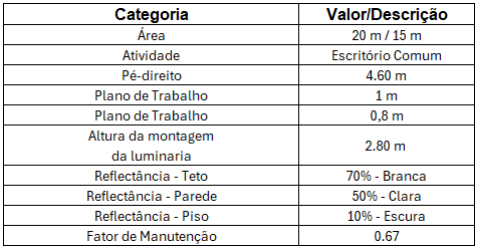
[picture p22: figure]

Fonte: Autoria do grupo

Figura 45 - Dados lâmpada

Fonte: Autoria do grupo

Foram selecionadas luminárias que utilizam lâmpadas fluorescentes de 4x32W. O

posicionamento das luminárias foi otimizado para assegurar uma distribuição homogênea da

luz em todo o ambiente.

Para a elaboração e análise do projeto luminotécnico no software DIALux evo, utilizou-

se como referência a norma Europa (EN 12464-1:2021), que trata da iluminação de locais de

trabalho. Embora a norma brasileira NBR ISO/CIE 8995-1 não estejam diretamente integrada

aos perfis padrão do software, a EN 12464-1:2021 é uma das normas mais completas,

atualizadas e internacionalmente reconhecidas para a qualidade da iluminação em ambientes

profissionais.

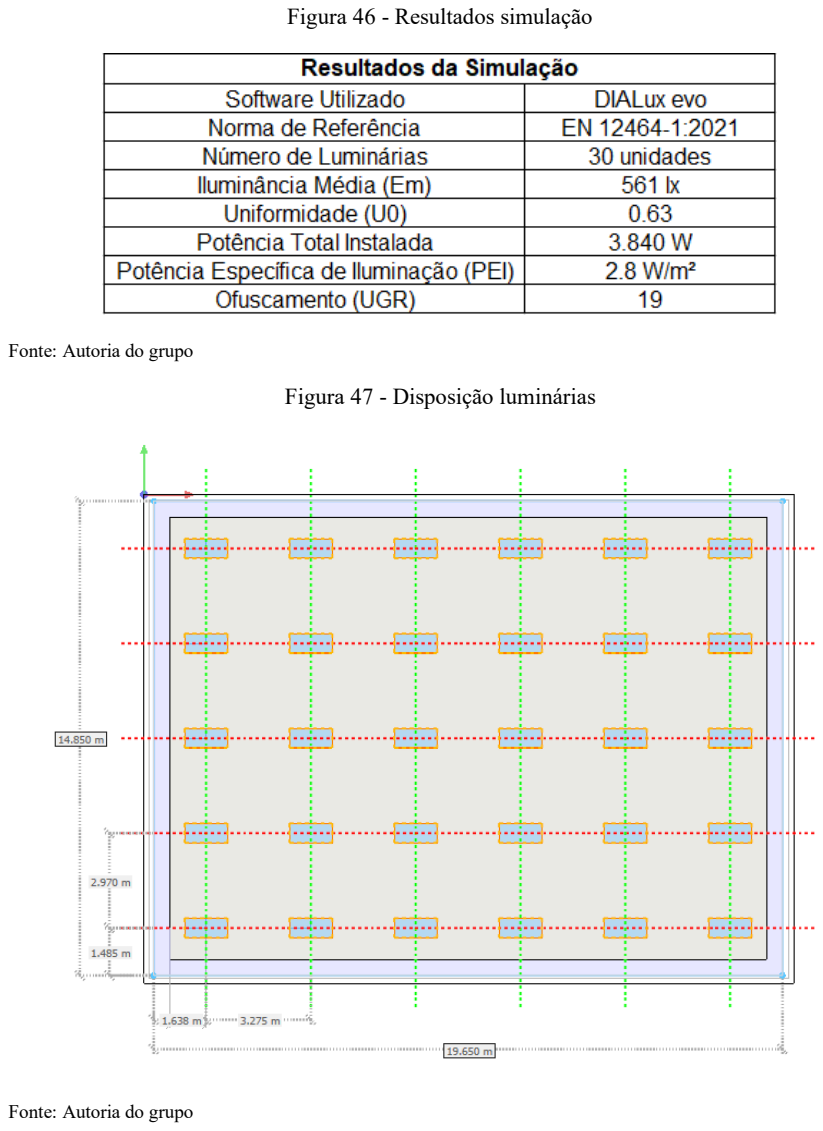
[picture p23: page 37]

Figura 46 - Resultados simulação

Fonte: Autoria do grupo

Figura 47 - Disposição luminárias

Fonte: Autoria do grupo

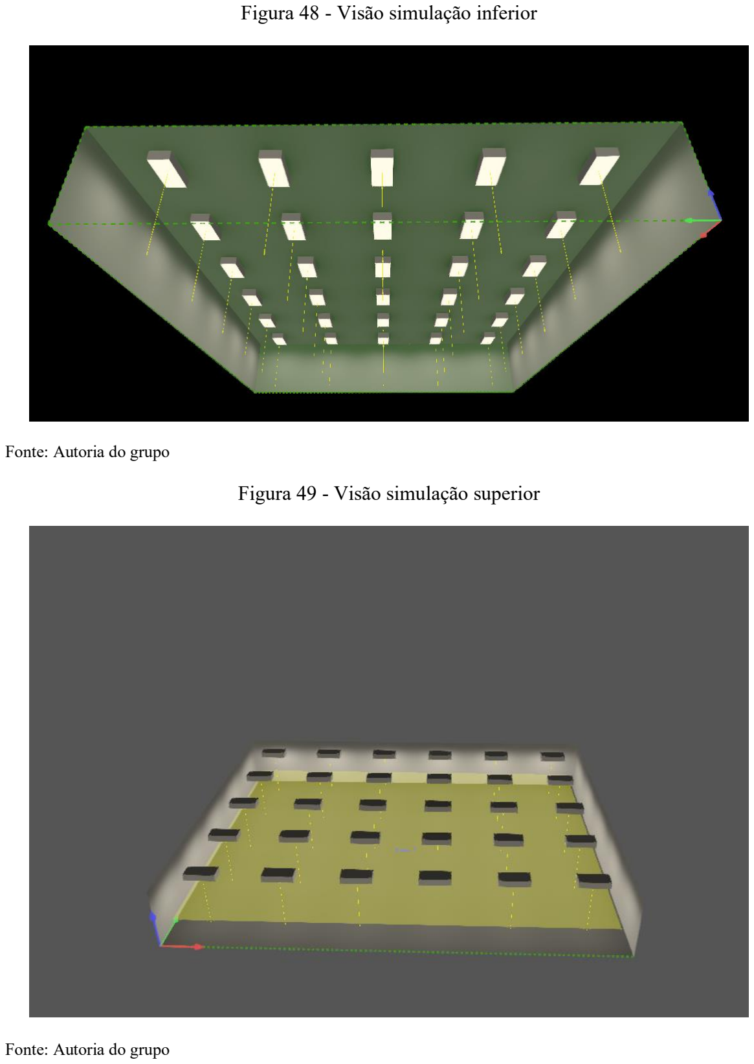
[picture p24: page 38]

Figura 48 - Visão simulação inferior

Fonte: Autoria do grupo

Figura 49 - Visão simulação superior

Fonte: Autoria do grupo

### 3 CONCLUSÃO

O projeto apresentado permitiu o desenvolvimento completo de um sistema elétrico

industrial, desde o levantamento de dados iniciais até a definição dos componentes essenciais,

como transformadores, condutores, disjuntores, inversores. As escolhas técnicas foram

baseadas em normas vigentes, especialmente a NBR 5410 e catálogos de fabricantes, de forma

a garantir segurança, eficiência e conformidade com os requisitos operacionais da indústria. A

análise de curto-circuito e o dimensionamento do sistema luminotécnico complementaram o

estudo, onde foi possível realizar a simulação em softwares como o Dialux e o PSP-UFU, para

complementar o estudo. Assim, o trabalho demonstrou a importância da integração entre teoria

e prática do conteúdo visto em aula e ao decorrer do curso.

### 4 REFERENCIA BIBLIOGRÁFICAS

GOMES, Caroline Fernandes da Silva; SANTOS, Victor Souza dos; VIEIRA,

Guilherme Pires; PIRES, Rachel Cristina Santos; FARIAS, Bruno Matos de. A

importância da elaboração de um projeto de instalações elétricas e seus requisitos normativos.

Epitaya | E-Books, | v. | 1, | n. | 15, | p. | 71–86, | 2020. | Disponível | em:

https://portal.epitaya.com.br/index.php/ebooks/article/view/97. Acesso em: 2 jun. 2025

SILVA, Iago de Melo; ALMEIRA, Brayan Lima de; SILVA, Sabrina Oliveira;

FERNANDES, Márcio da Silva. A importância do projeto elétrico e a análise da execução na

cidade de Paracatu-MG. Anais do 1º Simpósio de TCC das Faculdades FINOM e Tecsoma,

Paracatu, | MG, | 2019. | p. | 892–902. | Disponível | em:

https://www.finom.edu.br/assets/uploads/cursos/tcc/2021042217042012.pdf. Acesso em: 27

mai. 2025

WEG. Motor elétrico trifásico W22 IR3 Premium: catálogo técnico. Jaraguá do Sul:

WEG, 2022. Disponível em: https://static.weg.net/medias/downloadcenter/h94/h69/WEG-

w22-motor-eletrico-trifasico-50023622-brochure-portuguese-web.pdf. (https://static.weg.net/medias/downloadcenter/h94/h69/WEG-w22-motor-eletrico-trifasico-50023622-brochure-portuguese-web.pdf) Acesso em: 3 jun. 2025.

ASSOCIAÇÃO BRASILEIRA DE NORMAS TÉCNICAS. NBR 5410: Instalações

elétricas de baixa tensão. Rio de Janeiro: ABNT, 2004.

ASSOCIAÇÃO BRASILEIRA DE NORMAS TÉCNICAS. NBR 5356-11:

Transformadores de potência – Parte 11: Transformadores do tipo seco – Especificação. Rio

de Janeiro: ABNT, 2016

KRUGER, Tarcísio Pollnow. Dimensionamento de condutores. São José: Instituto

Federal | de | Santa | Catarina | (IFSC), | 2016. | Disponível | em:

https://wiki.sj.ifsc.edu.br/images/4/47/Dimensionamento_Condutores.pdf. Acesso em: 1 jun.

2025

SIEMENS. Siemens Brasil. Disponível em: https://www.siemens.com/br/pt.html.

Acesso em: 20 mai. 2025

ASSOCIAÇÃO BRASILEIRA DE NORMAS TÉCNICAS (ABNT). NBR 14039: instalações elétricas de média tensão, de 1,0 kV a 36,2 kV. Rio de Janeiro, 2005.

WEG. CFW11: catálogo de inversores de frequência. [S. l.]: WEG, 2020. Disponível

em: https://static.weg.net/medias/downloadcenter/h88/h14/WEG-CFW11-catalogo-10510201-

pt.pdf. (https://static.weg.net/medias/downloadcenter/h88/h14/WEG-CFW11-catalogo-10510201-pt.pdf) Acesso em: 3 jun. 2025

WEG. Manual do Usuário CFW11: inversores de frequência modelos Mec-F a H. [S.

l.]: WEG, [ano de publicação]. Disponível em: https://www.servicedrive.com.br/wp-

content/uploads/Manual-do-Usuário-CFW11-Mec-F-a-H-PTBR-ServiceDrive-19-3012-

6360.pdf. (https://www.servicedrive.com.br/wp-content/uploads/Manual-do-Usu%C3%A1rio-CFW11-Mec-F-a-H-PTBR-ServiceDrive-19-3012-6360.pdf) Acesso em: 5 jun. 2025

MORETTI, José Carlos. NTC 903100: Fornecimento em tensão primária de

distribuição. | Curitiba: | Universidade | Federal do | Paraná, | 2013. | Disponível | em:
http://www.moretti.agrarias.ufpr.br/eletrificacao_rural/livro_copel_ntc_903100.pdf. | Acesso

em: 5 jun. 2025.

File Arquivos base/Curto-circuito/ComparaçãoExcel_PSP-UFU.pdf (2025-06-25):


Curto-circuito

- Ponto de entrega PSP-UFU

Curto-circuito trifásico

Curto-circuito fase-terra

Ponto de entrega Excel

- Secundário do transformador PSP-UFU

Curto-circuito trifásico

Curto-circuito fase-terra

Ponto de entrega Excel


- QGF PSP-UFU

Curto-circuito trifásico

Curto-circuito fase-terra

QGF Excel

- CCM ÁREA 1 PSP-UFU

Curto-circuito trifásico

Curto-circuito fase-terra

CCM Área 1 Excel

- CCM ÁREA 2 PSP-UFU

Curto-circuito trifásico

Curto-circuito fase-terra

CCM Área 2 Excel


- CCM ÁREA 3 PSP-UFU

Curto-circuito trifásico

Curto-circuito fase-terra


CCM Área 3 Excel

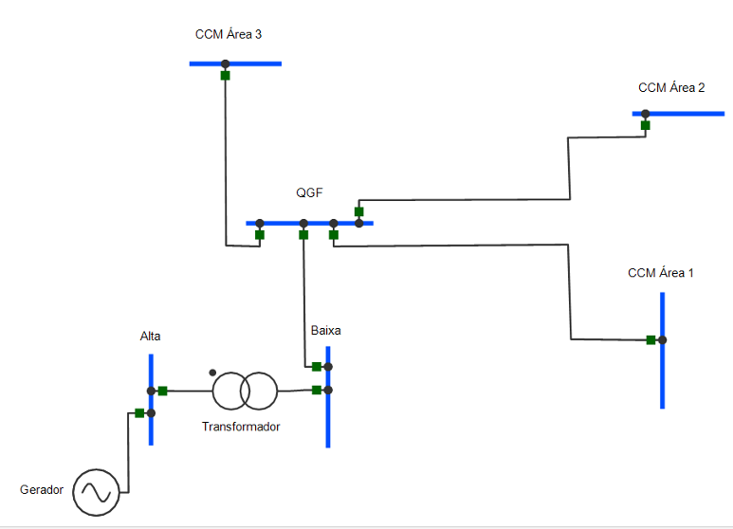
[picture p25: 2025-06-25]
Arquivos base/Curto-circuito/Sistema elétrico PSP.PNG

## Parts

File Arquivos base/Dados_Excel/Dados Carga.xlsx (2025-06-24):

DESCRICAO | Dados das Cargas |  |  |  | Qtd De Cicuitos | FCA | FCT (30°) | Corrente de Projeto Corrigida I'p (A) | Disjuntor (A) | Fabricante | Modelo
 | Tensao (V) | Potencia Aparente(kVA) | Fator de Potencia (FP) | Corrente de Projeto Ip (A)
CARGA GERAL QGF | 380 | 685.35 | 0.92 | 1125.2 | 1 | 1 | 1 | 1125.22 | 1250 A | SIEMENS | 3WJ11122
ÁREA 1 | 380 | 315.84 | 0.82 | 500.1 | 3 | 0.82 | 1 | 609.85 | 600 | SIEMENS | 3VA1463
ÁREA 2 | 380 | 125.69 | 0.92 | 200.2 | 3 | 0.82 | 1 | 244.16 | 250 | SIEMENS | 3VA1225
ÁREA 3 | 380 | 279.35 | 0.92 | 424.9 | 3 | 0.82 | 1 | 518.21 | 600 | SIEMENS | 3VA1463
MOTOR 1 | 380 | 66.27 | 0.83 | 105.22 | 12 | 0.78 | 1 | 134.89 | 125A | SIEMENS | 3VM1112
MOTOR 2 | 380 | 91.46 | 0.82 | 144.62 | 12 | 0.78 | 1 | 185.42 | 160A | SIEMENS | 3VM1116
MOTOR 3 | 380 | 27.16 | 0.81 | 43.81 | 12 | 0.78 | 1 | 56.17 | 50A | SIEMENS | 3VM1115
MOTOR 4 | 380 | 130.95 | 0.84 | 206.42 | 12 | 0.78 | 1 | 264.64 | 250A | SIEMENS | 3VM2225
MOTOR 5 | 380 | 13.75 | 0.8 | 22.47 | 12 | 0.78 | 1 | 28.8 | 32A | SIEMENS | 3VM1132
MOTOR 6 | 380 | 66.27 | 0.83 | 105.22 | 12 | 0.78 | 1 | 134.89 | 125A | SIEMENS | 3VM1125
MOTOR 7 | 380 | 45.68 | 0.81 | 72.53 | 12 | 0.78 | 1 | 92.99 | 100A | SIEMENS | 3VM1110
AUXILIAR | 380 | 97.83 | 0.92 | 148.81 | 12 | 0.78 | 1 | 190.78 | 160A | SIEMENS | 3VM1116
AUXILIAR | 380 | 81.52 | 0.92 | 124.01 | 12 | 0.78 | 1 | 158.98 | 160A | SIEMENS | 3VM1116
AQUECIMENTO 1 | 380 | 35 | 1 | 53.24 | 12 | 0.78 | 1 | 68.26 | 80A | SIEMENS | 3VM1180
AQUECIMENTO 2 | 380 | 25 | 1 | 38.03 | 12 | 0.78 | 1 | 48.75 | 50A | SIEMENS | 3VM1150
AQUECIMENTO 3 | 380 | 40 | 1 | 60.85 | 12 | 0.78 | 1 | 78.01 | 80A | SIEMENS | 3VM1180
DESCRICAO | Dados das Cargas |  |  |  | Metodo de Instalação | FCA | FCT (30°) | Corrente de Projeto Corrigida I'p (A)
 | Tensao (V) | Potencia Aparente(kVA) | Fator de Potencia (FP) | Corrente de Projeto Ip (A)
CARGA GERAL QGF | 380 | 685.35 | 0.92 | 1125.2 | Canaleta fechada no piso, solo ou parede | 1 | 1 | 1125.22
ÁREA 1 | 380 | 315.84 | 0.82 | 500.1 | Leitos, suportes horizontais ou telas 14/16 - F E | 0.82 | 1 | 609.85
ÁREA 2 | 380 | 125.69 | 0.92 | 200.2 | Leitos, suportes horizontais ou telas 14/16 - F E | 0.82 | 1 | 244.16
ÁREA 3 | 380 | 279.35 | 0.92 | 424.9 | Leitos, suportes horizontais ou telas 14/16 - F E | 0.82 | 1 | 518.21
MOTOR 1 | 380 | 66.27 | 0.83 | 105.22 | Leitos, suportes horizontais ou telas 14/16 - F E | 0.78 | 1 | 134.89
MOTOR 2 | 380 | 91.46 | 0.82 | 144.62 | Leitos, suportes horizontais ou telas 14/16 - F E | 0.78 | 1 | 185.42
MOTOR 3 | 380 | 27.16 | 0.81 | 43.81 | Leitos, suportes horizontais ou telas 14/16 - F E | 0.78 | 1 | 56.17
MOTOR 4 | 380 | 126.4 | 0.87 | 199.3 | Leitos, suportes horizontais ou telas 14/16 - F E | 0.78 | 1 | 255.52
MOTOR 5 | 380 | 13.75 | 0.8 | 22.47 | Leitos, suportes horizontais ou telas 14/16 - F E | 0.78 | 1 | 28.8
MOTOR 6 | 380 | 66.27 | 0.83 | 105.22 | Leitos, suportes horizontais ou telas 14/16 - F E | 0.78 | 1 | 134.89
MOTOR 7 | 380 | 45.68 | 0.81 | 72.53 | Leitos, suportes horizontais ou telas 14/16 - F E | 0.78 | 1 | 92.99
AUXILIAR | 380 | 97.83 | 0.92 | 148.81 | Leitos, suportes horizontais ou telas 14/16 - F E | 0.78 | 1 | 190.78
AUXILIAR | 380 | 81.52 | 0.92 | 124.01 | Leitos, suportes horizontais ou telas 14/16 - F E | 0.78 | 1 | 158.98
AQUECIMENTO 1 | 380 | 35 | 1 | 53.24 | Leitos, suportes horizontais ou telas 14/16 - F E | 0.78 | 1 | 68.26
AQUECIMENTO 2 | 380 | 25 | 1 | 38.03 | Leitos, suportes horizontais ou telas 14/16 - F E | 0.78 | 1 | 48.75
AQUECIMENTO 3 | 380 | 40 | 1 | 60.85 | Leitos, suportes horizontais ou telas 14/16 - F E | 0.78 | 1 | 78.01

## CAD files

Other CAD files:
Arquivos base/Unifilar/UNIFILAR GERAL.dwg

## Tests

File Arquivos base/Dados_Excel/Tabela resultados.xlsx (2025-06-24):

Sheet: 1 - Dados iniciais de cargas
Setor | Carga | Potência mecânica (cv) | Fator de potência | Rendimento | Potência ativa (kW) | Potência reativa (kVAr) | Potência aparente (kVA)
1 | Motor 1 | 75 | 0.83 | 0.958 | 55 | 30.68 | 66.27
 | Motor 2 | 100 | 0.82 | 0.962 | 75 | 42.93 | 91.46
 | Motor 3 | 30 | 0.81 | 0.943 | 22 | 12.90 | 27.16
 | Motor 4 | 150 | 0.87 | 0.965 | 110 | 54.23 | 126.44
2 | Motor 5 | 15 | 0.8 | 0.931 | 11 | 6.60 | 13.75
 | Motor 6 | 75 | 0.83 | 0.958 | 55 | 30.68 | 66.27
 | Motor 7 | 50 | 0.81 | 0.954 | 37 | 21.70 | 45.68
3 | Auxiliar | - | 0.92 | - | 90 | 35.27 | 97.83
 | Auxiliar | - | 0.92 | - | 75 | 29.39 | 81.52
 | Aquecimento 1 | - | 1 | - | 35 | 0 | 35
 | Aquecimento 2 | - | 1 | - | 25 | 0 | 25
 | Aquecimento 3 | - | 1 | - | 40 | 0 | 40

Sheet: 2 - Dados condutores áreas
Area | Carga | Potência mecânica (CV) | Potência aparente (kVA) | Cabo mm² Ampacidade | Cabo mm² Queda de tensão | Cabo mm² Seção mínima | Cabo mm² Escolhido
1 | Motor 1 | 75 | 66.27 | 35 mm² | 2,5 mm² | 2,5 mm² | 35 mm²
 | Motor 2 | 100 | 91.46 | 70 mm² | 2,5 mm² | 2,5 mm² | 70 mm²
 | Motor 3 | 30 | 27.16 | 10 mm² | 2,5 mm² | 2,5 mm² | 10 mm²
 | Motor 4 | 150 | 130.95 | 95 mm² | 4 mm² | 2,5 mm² | 95 mm²
2 | Motor 5 | 15 | 13.75 | 4 mm² | 2,5 mm² | 2,5 mm² | 4 mm²
 | Motor 6 | 75 | 66.27 | 35 mm² | 2,5 mm² | 2,5 mm² | 35 mm²
 | Motor 7 | 50 | 45.68 | 25 mm² | 2,5 mm² | 2,5 mm² | 25 mm²
3 | Auxiliar | - | 97.83 | 70 mm² | 2,5 mm² | 2,5 mm² | 70 mm²
 | Auxiliar | - | 81.52 | 50 mm² | 2,5 mm² | 2,5 mm² | 50 mm²
 | Aquecimento 1 | - | 35 | 16 mm² | 2,5 mm² | 2,5 mm² | 16 mm²
 | Aquecimento 2 | - | 25 | 10 mm² | 2,5 mm² | 2,5 mm² | 10 mm²
 | Aquecimento 3 | - | 40 | 16 mm² | 2,5 mm² | 2,5 mm² | 16 mm²

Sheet: 3 - Dados condutores QGF-áreas
Area | Potência ativa (kW) | Potência reativa (kVAr) | Potência aparente (kVA) | Cabo mm² Ampacidade | Cabo mm² Queda de tensão | Cabo mm² Seção mínima | Cabo mm² Escolhido | Disjuntor BT
1 | 262 | 140.74 | 311.33 | 2x120mm² | 70mm² | 2,5 mm² | 2x120mm² | 600A
2 | 103 | 58.97 | 125.69 | 95mm² | 35mm² | 2,5 mm² | 95mm² | 250A
3 | 265 | 64.67 | 279.35 | 2x120mm² | 70mm² | 2,5 mm² | 2x120mm² | 600A

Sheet: 4 - Dados de curto-circuito
Setor | Corrente de curto-circuito
 | trifásico (Ics) - kA | monofásico franco (Icft) - kA | Fator de assimetria | Corrente de curto assimétrica (Ica) - kA
Ponto de entrega | 8.20 | 6.81 | 50.00 | 1.69
Secundário do transformador | 33.71 | 32.94 | 3.53 | 1.35
QGF | 30.21 | 22.32 | 3.17 | 1.31
Barramento área 1 | 23.45 | 10.81 | 1.74 | 1.15
Barramento área 2 | 14.67 | 5.52 | 0.94 | 1.02
Barramento área 3 | 19.87 | 9.80 | 1.23 | 1.08

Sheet: Cabo QGF
Setor | Potência ativa (kW) | Potência reativa (kVAr) | Potência aparente (kVA) | Cabo mm² Ampacidade | Cabo mm² Queda de tensão | Cabo mm² Seção mínima | Cabo mm² Escolhido | Disjuntor BT
1 | 630 | 264.38 | 683.23 | 4x185mm² | 50mm² | 2,5 mm² | 4x185mm² | 600A

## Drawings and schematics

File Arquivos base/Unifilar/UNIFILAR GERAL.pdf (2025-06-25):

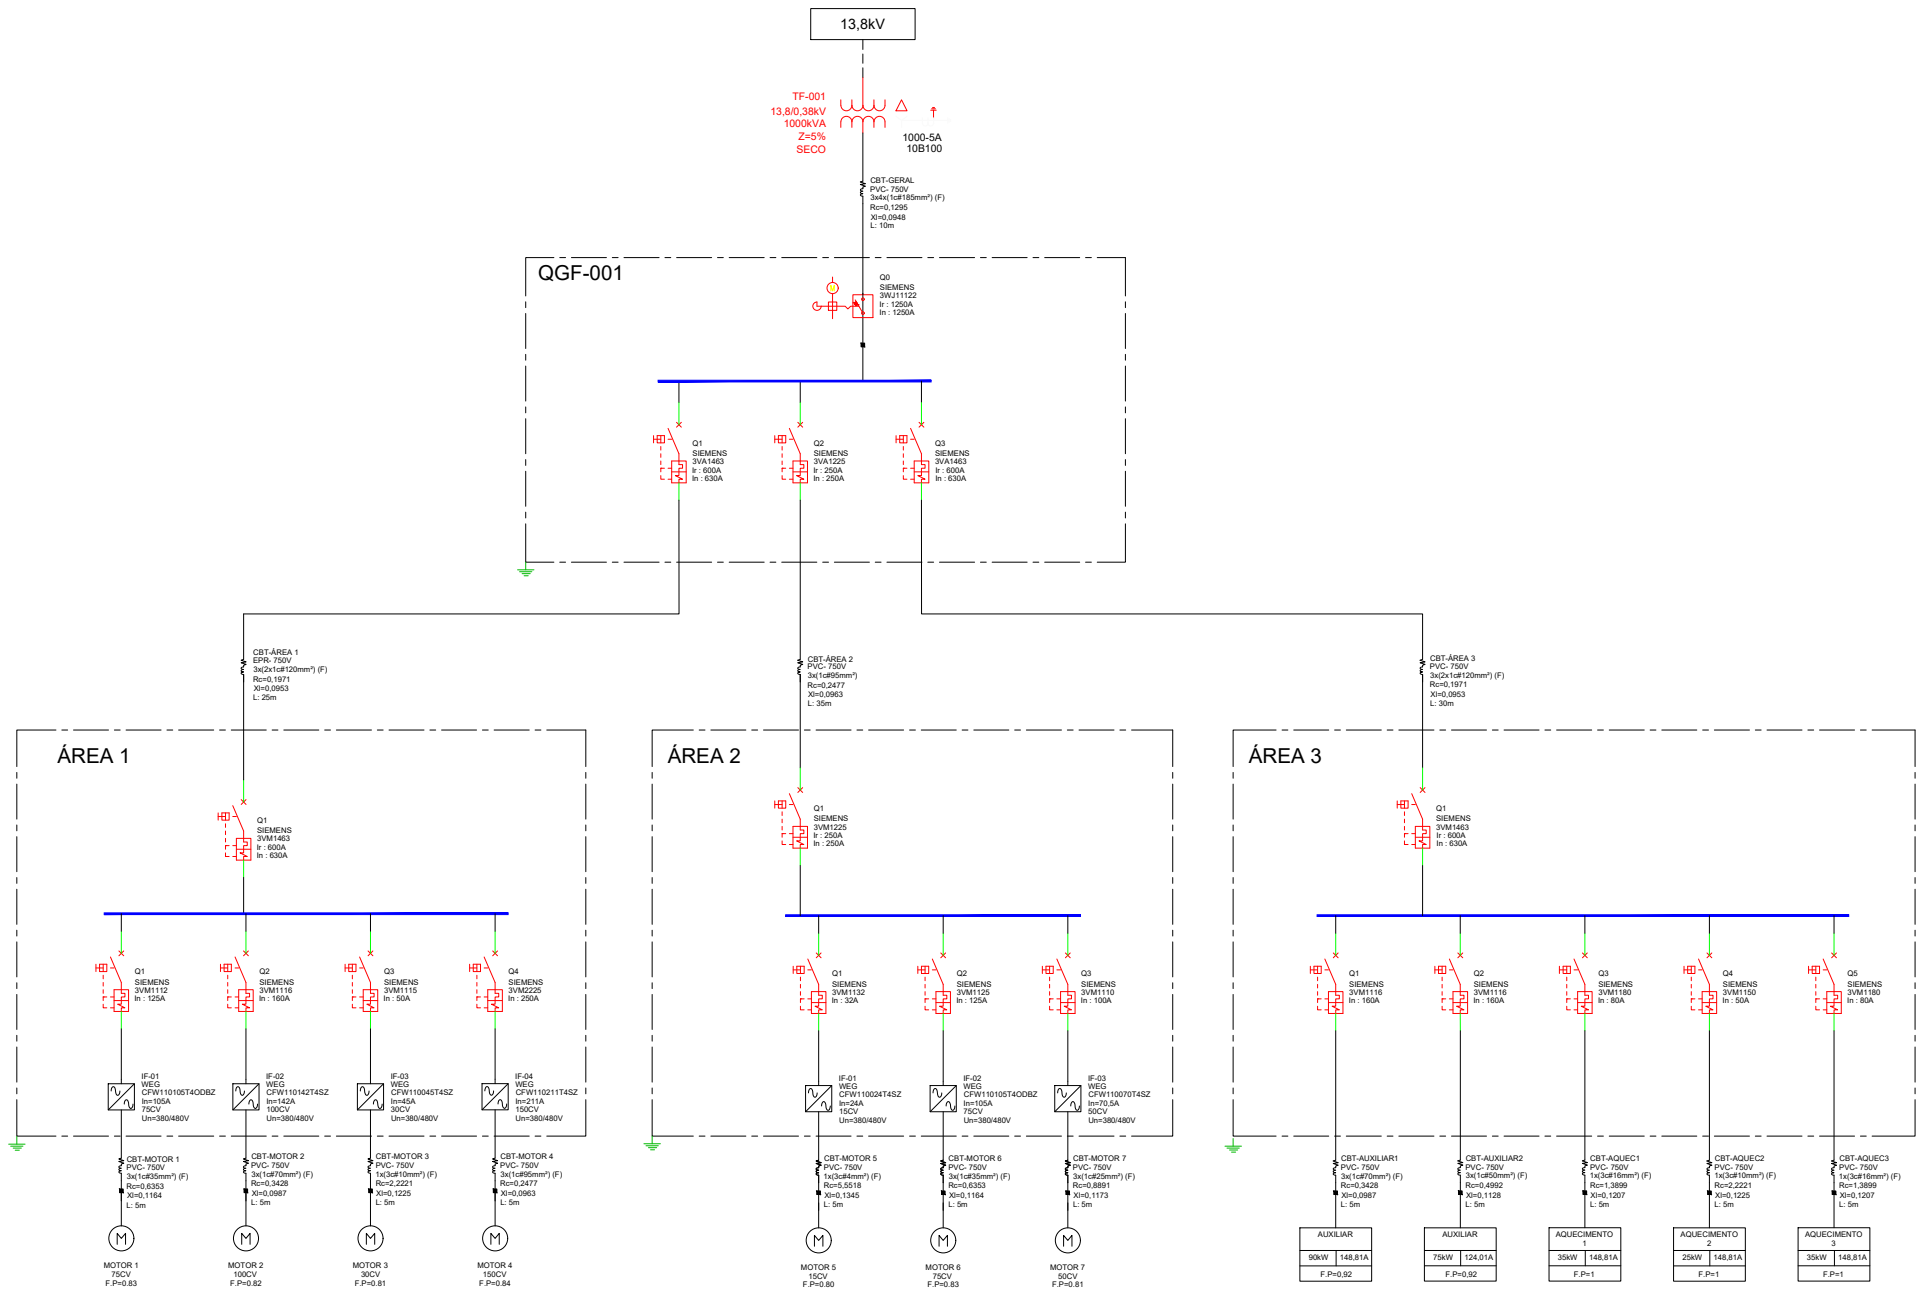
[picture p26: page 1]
CBT-ÁREA 1 EPR- 750V; 3x(2x1c#120mm²) (F); ÁREA 1; ÁREA 2; PVC- 750V; CBT-ÁREA 2; MOTOR 5; MOTOR 6; MOTOR 7; MOTOR 1; MOTOR 2; MOTOR 3; MOTOR 4; ÁREA 3; CBT-ÁREA 3; CBT-MOTOR 7 PVC- 750V; CBT-MOTOR 6 PVC- 750V; CBT-MOTOR 5; 1x(3c#4mm²) (F); CBT-MOTOR 4; 3x(1c#95mm²) (F); CBT-MOTOR 3; 1x(3c#10mm²) (F); CBT-MOTOR 2; 3x(1c#70mm²) (F); CBT-MOTOR 1; 3x(1c#35mm²) (F); 3x4x(1c#185mm²) (F); 3x(1c#25mm²) (F); 3x(1c#50mm²) (F); 1x(3c#16mm²) (F)
